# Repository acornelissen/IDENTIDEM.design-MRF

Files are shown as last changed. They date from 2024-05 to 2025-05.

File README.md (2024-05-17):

# IDENTIDEM.design M(edium Format) (R)ange(F)inder

**Before anything else, a big thank you to Oscar from Panomicron for making the CAD files for his [Thulium 6x9](https://www.panomicron.com/thulium) available for download. This camera is a heavily modified version of the Thulium, and wouldn't exist if it wasn't for Oscar's excellent work.**

My goal for this camera was to build _my_ ideal medium format rangefinder using what I learned from designing and building the LRF45, with no limits on complexity, cost, and time. As I kept working on it, it evolved and evolved, and I think I've finally reached that goal.

The detailed build guide should drop soon(ish). For now though, everything you need to build one of your own modern medium format rangefinders is in this repository.

## Features
- Uses "LiDAR" to measure distance to subject (not true LiDAR, but a ToF sensor that uses a focused IR LED array) 
- Can be used with any Mamiya Universal Press lens and couples to the original lens rangefinder mechanism with a high-precision linear position sensor
- This means that the lens position and distance measured is electronically coupled, making this the first multi-lens, electronically coupled rangefinder that I know of
- In addition, there is an intuitive in-camera lens calibration routine to make sure your camera and lens work together perfectly
- Multi-format, with masks for 6x7, 6x6, 6x4.5 and 35mm Panoramics
- Uses a high-precision rotary encoder coupled to the take-up spool to count revolutions, which is then used to accurately count frames regardless of selected format
- Built-in lightmeter
- Built-in accelerometer / gyro
- In-viewfinder OLED display with:
  - Lightmeter information: Selected ISO, selected aperture, and calculated shutter speed
  - Lens focus distance
  - Distance to subject
  - Frame lines that adjust according to selected lens
  - Masking that adjusts to selected format
  - Reticle for focus that indicates focus accuracy as lens focus distance and distance to subject converges
  - Horizon indicator
- External OLED display with:
  - Frame counter
  - Battery life percentage
  - Selected format
  - Selected lens
- Open source! 

## Bill of Materials
See the Build Guide PDF for the BoM. 

---
🍺 <strong><a href="https://paypal.me/albertcor">Buy me a beer</a></strong> if you'd like to say thank you.

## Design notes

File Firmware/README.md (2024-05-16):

This is a Arduino C++ rewrite of the LRF45 CircuitPython code that was adapted for use in my medium format LiDAR rangefinder. 
With the amount of sensors I am using on this camera, as well as needing to drive two displays, the CircuitPython performance was not acceptable, even running on a better MCU.

This code was built for the Adafruit Feather ESP32-S3 (I am using the 4MB Flash 2MB PSRAM version, but the one without PSRAM should work just as well). It's a nice board with a built in LiPO charger and battery monitor, 
so no need to faff about with voltage dividers and guesstimate how much battery is left.

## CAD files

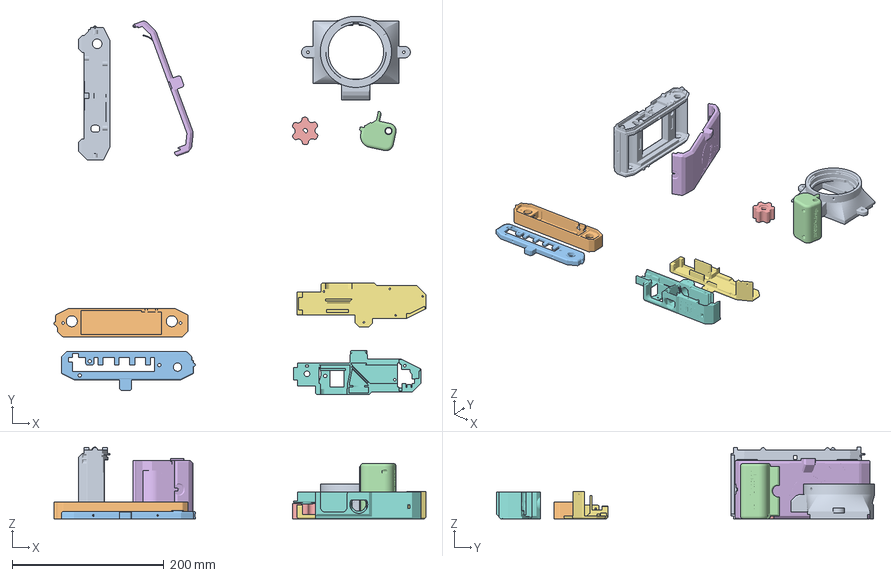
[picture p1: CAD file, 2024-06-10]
OrcaSlicer/main-parts.3mf
490.9 x 499.4 x 94.8 mm
body-main
body-bottom
top-plate
grip
advance-knob
door-back
viewfinder-cover
viewfinder
lenscone-mamiya-press-thick-wall

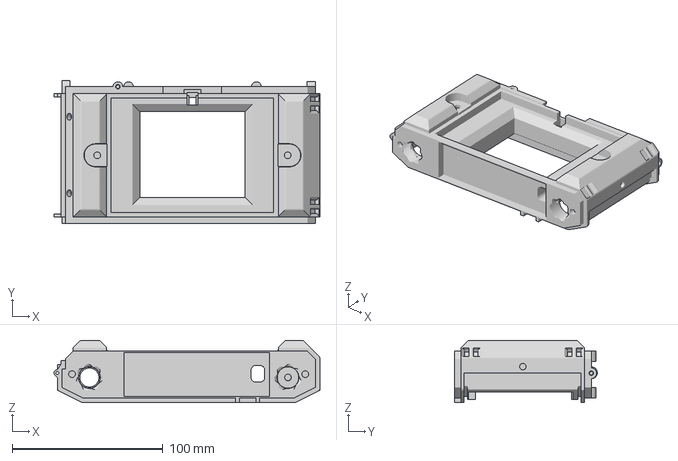
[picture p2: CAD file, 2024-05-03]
3MF/Main Parts/body-main.3mf
176.8 x 94.8 x 41.5 mm

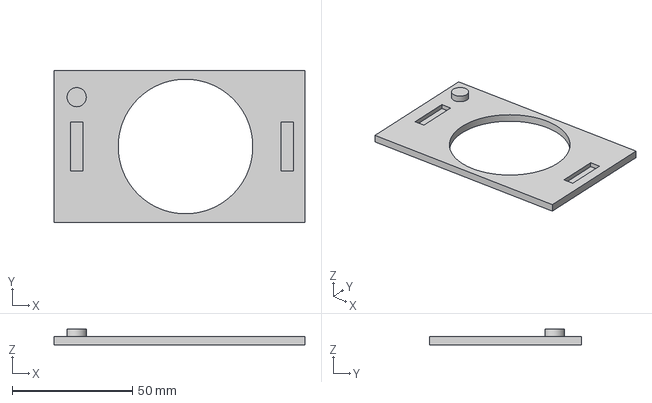
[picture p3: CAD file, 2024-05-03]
3MF/Film Masks/6x6 Circle.3mf
104.5 x 63.1 x 6.50 mm

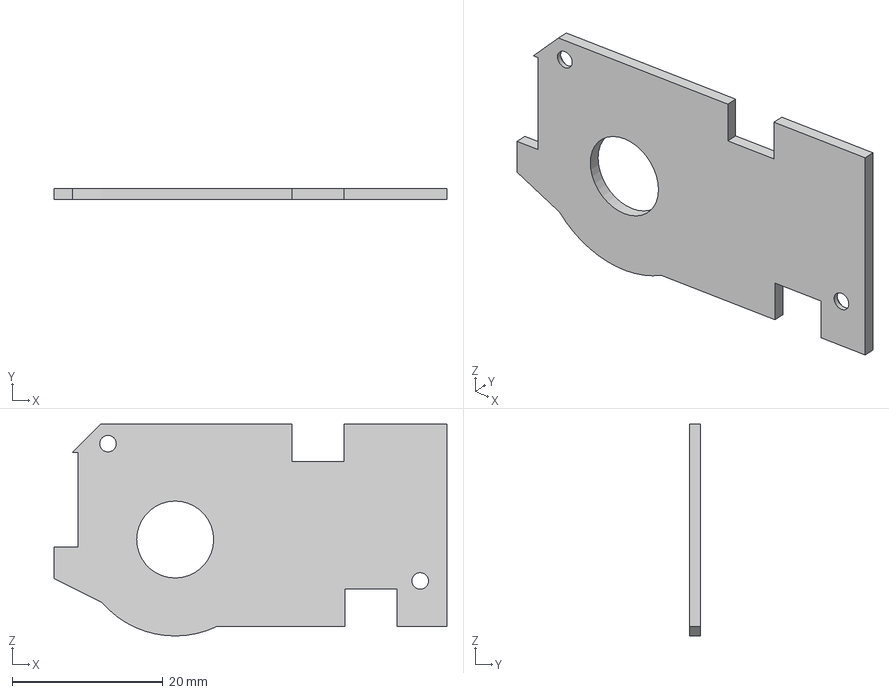
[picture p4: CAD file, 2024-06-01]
3MF/Fine Parts/advance-plate.3mf
52.1 x 1.50 x 28.1 mm

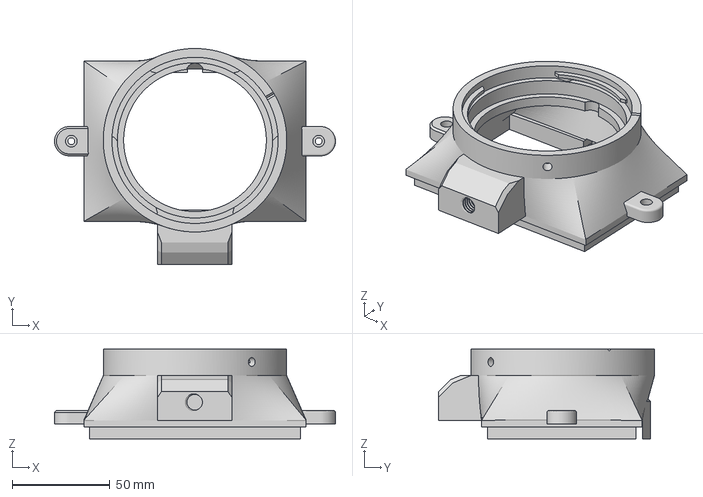
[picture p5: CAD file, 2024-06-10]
3MF/Main Parts/lenscone-mamiya-press.3mf
143.8 x 110.5 x 46.0 mm

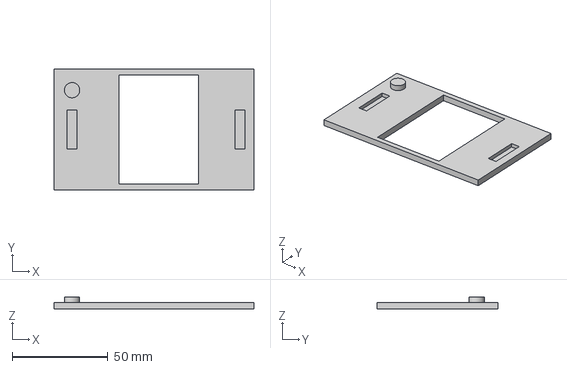
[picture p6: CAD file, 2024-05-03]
3MF/Film Masks/6x4.5.3mf
104.5 x 63.1 x 6.50 mm

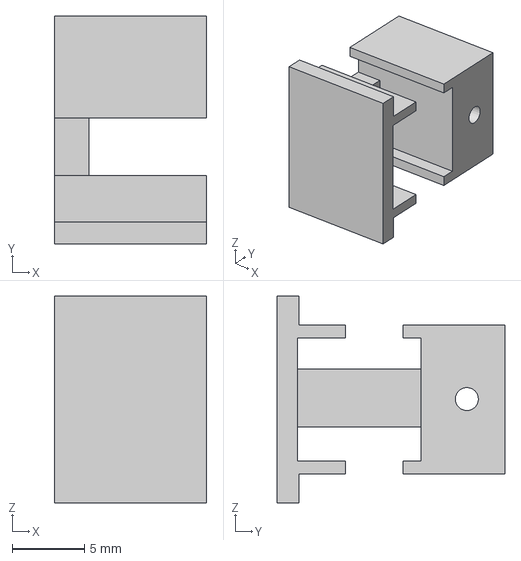
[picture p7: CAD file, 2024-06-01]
3MF/Fine Parts/button-plate.3mf
10.5 x 15.8 x 14.3 mm

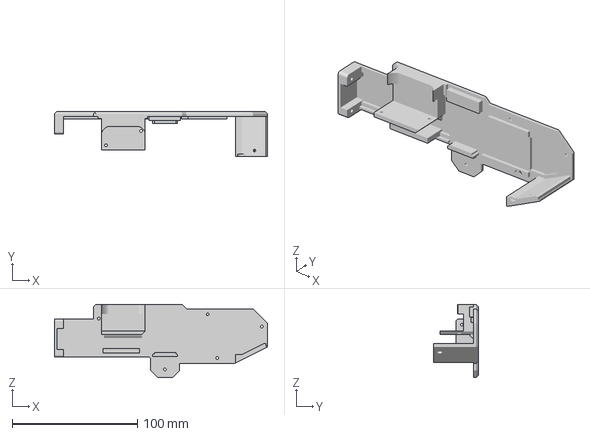
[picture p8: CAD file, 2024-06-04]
3MF/Main Parts/viewfinder-cover.3mf
170.1 x 36.2 x 58.4 mm

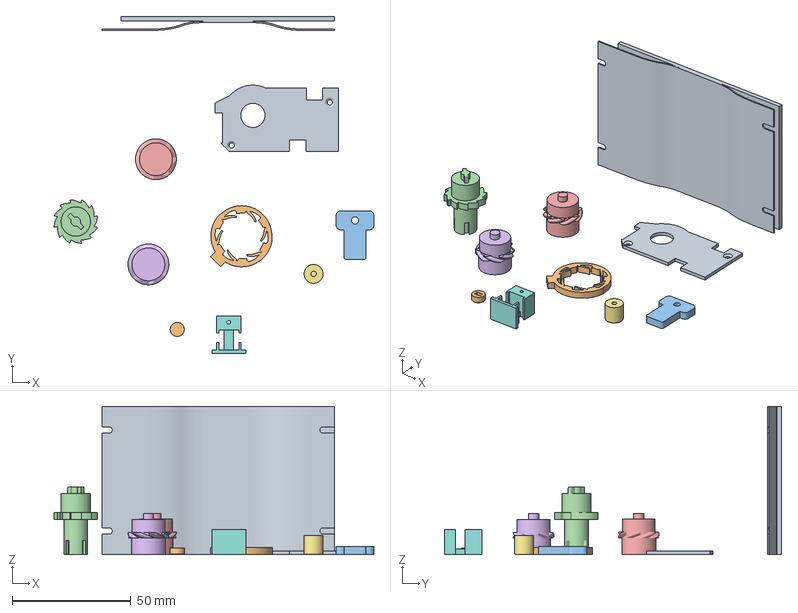
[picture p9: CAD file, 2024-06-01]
OrcaSlicer/fine-parts.3mf
135.0 x 142.1 x 62.6 mm
pressure-plate
advance-ratchet
spool-key (optional)
advance-post
right (from back) spool
left (from back) spool
sensor-nubbin
advance-plate
button

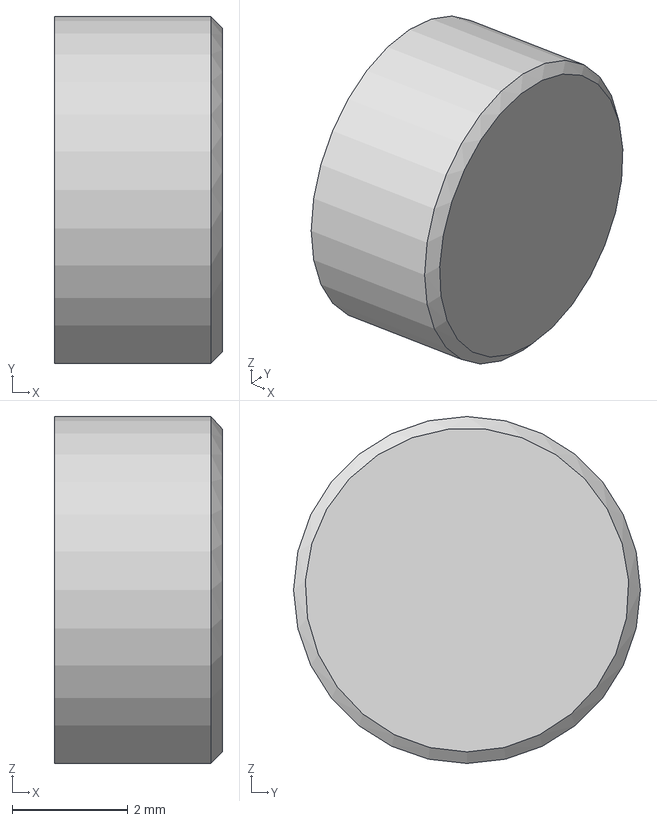
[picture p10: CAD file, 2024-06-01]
3MF/Fine Parts/button.3mf
2.91 x 6.00 x 6.00 mm

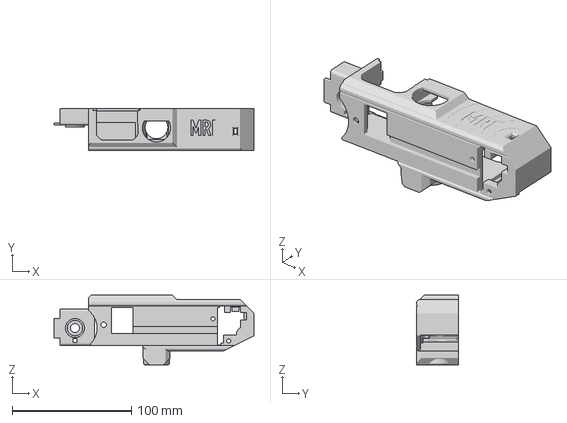
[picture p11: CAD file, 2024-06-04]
3MF/Main Parts/viewfinder.3mf
168.0 x 35.6 x 58.4 mm

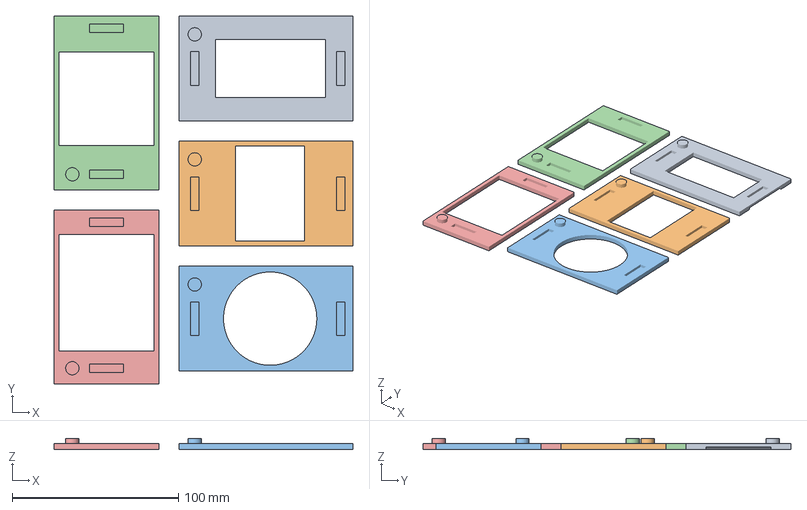
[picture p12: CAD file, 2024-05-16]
OrcaSlicer/film-masks.3mf
179.6 x 221.0 x 6.50 mm
35mm Pano
6x4.5
6x6 Circle
6x6
6x7

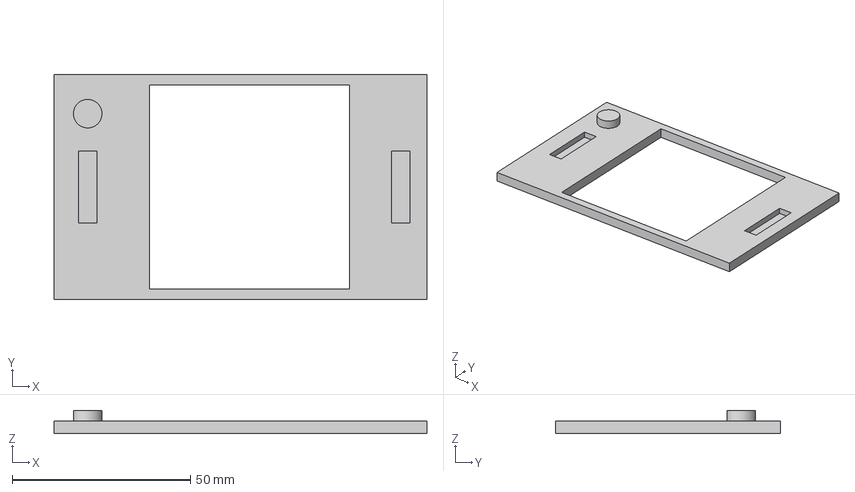
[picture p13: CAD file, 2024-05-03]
3MF/Film Masks/6x6.3mf
104.5 x 63.1 x 6.50 mm

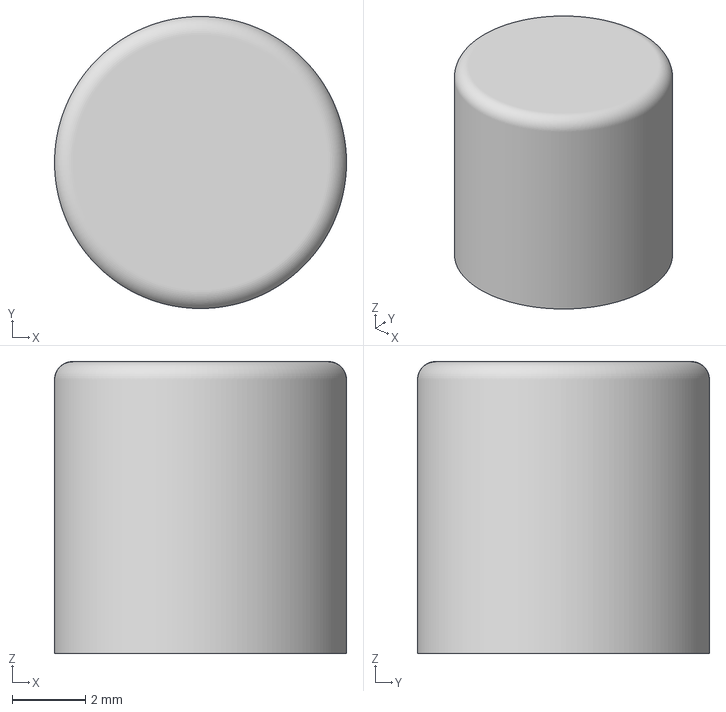
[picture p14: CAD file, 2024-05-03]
3MF/Fine Parts/sensor-nubbin.3mf
8.00 x 8.00 x 8.00 mm

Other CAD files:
3MF/Film Masks/35mm Pano.3mf
3MF/Main Parts/door-back.3mf
3MF/Film Masks/6x7.3mf
3MF/Fine Parts/pressure-plate.3mf
3MF/Fine Parts/advance-post.3mf
3MF/Fine Parts/advance-ratchet.3mf
3MF/Fine Parts/left (from back) spool.3mf
3MF/Fine Parts/right (from back) spool.3mf
3MF/Fine Parts/spool-key (optional).3mf
3MF/Main Parts/advance-knob.3mf
3MF/Main Parts/body-bottom.3mf
3MF/Main Parts/grip.3mf
3MF/Main Parts/top-plate.3mf

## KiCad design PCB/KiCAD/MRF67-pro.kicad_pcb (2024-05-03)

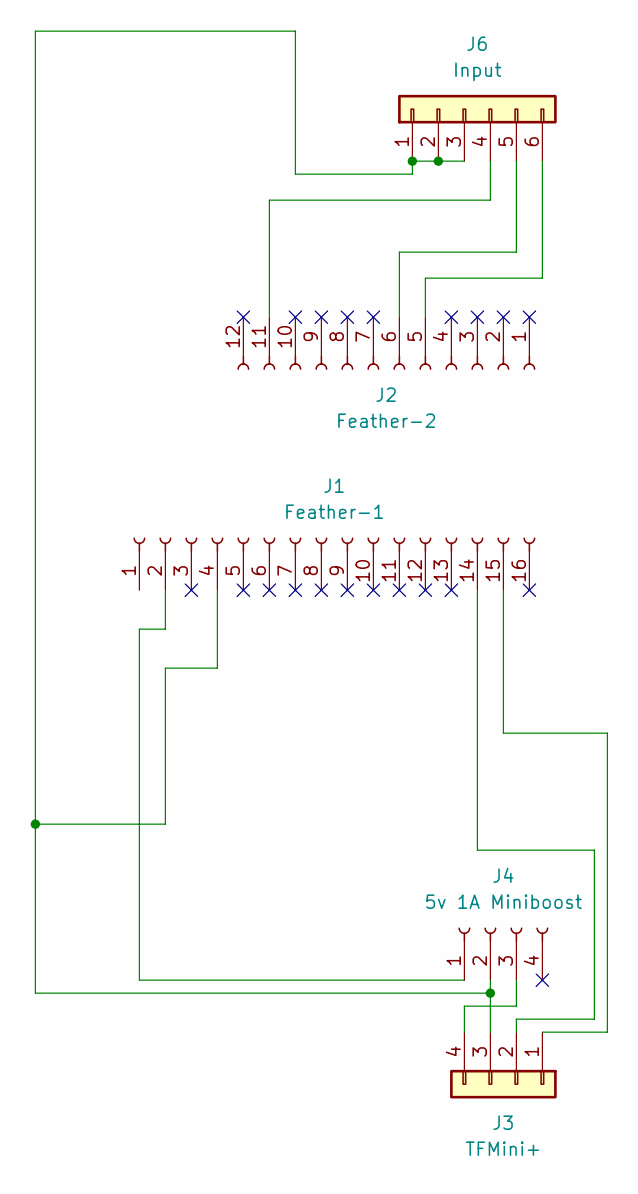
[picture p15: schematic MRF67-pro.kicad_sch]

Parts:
J1: Feather-1; PinHeader_1x16_P2.54mm_Vertical
J2: Feather-2; PinHeader_1x12_P2.54mm_Vertical
J3: TFMini+; JST_XH_B4B-XH-A_1x04_P2.50mm_Vertical
J4: 5v 1A Miniboost; PinHeader_1x04_P2.54mm_Vertical
J6: Input; JST_XH_B6B-XH-AM_1x06_P2.50mm_Vertical

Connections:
unnamed: J1.2, J4.1
unnamed: J1.4, J3.3, J4.2, J6.1, J6.2, J6.3
unnamed: J1.14, J3.2
unnamed: J1.15, J3.1
unnamed: J2.5, J6.6
unnamed: J2.6, J6.5
unnamed: J2.11, J6.4
unnamed: J3.4, J4.3

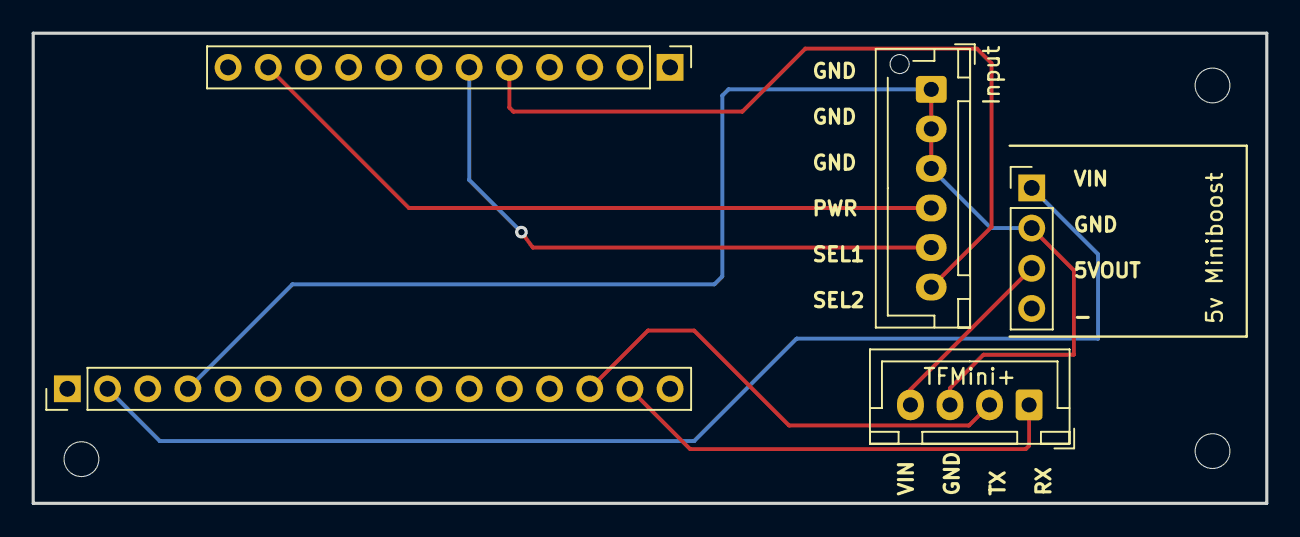
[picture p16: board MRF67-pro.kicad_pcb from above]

Board: 2 copper layers, 78.0 x 29.7 mm, 5 parts (0 on the bottom side), 8 nets.

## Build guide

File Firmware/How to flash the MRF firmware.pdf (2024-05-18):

# How to flash the MRF firmware

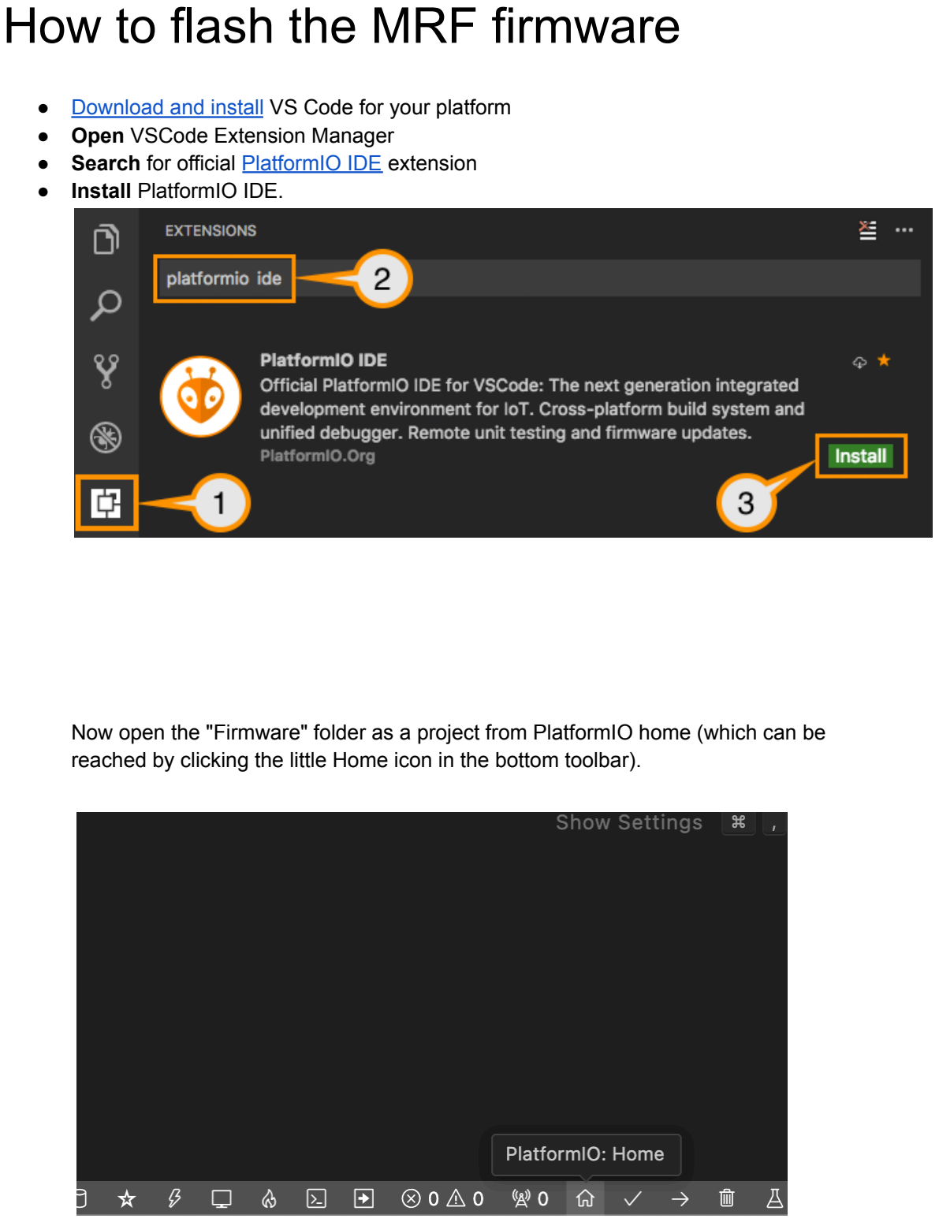
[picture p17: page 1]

- Download and install (https://code.visualstudio.com/download) VS Code for your platform
- Open VSCode Extension Manager
- Search for official PlatformIO IDE (https://marketplace.visualstudio.com/items?itemName=platformio.platformio-ide) extension
- Install PlatformIO IDE.

Now open the "Firmware" folder as a project from PlatformIO home (which can be reached by clicking the little Home icon in the bottom toolbar).

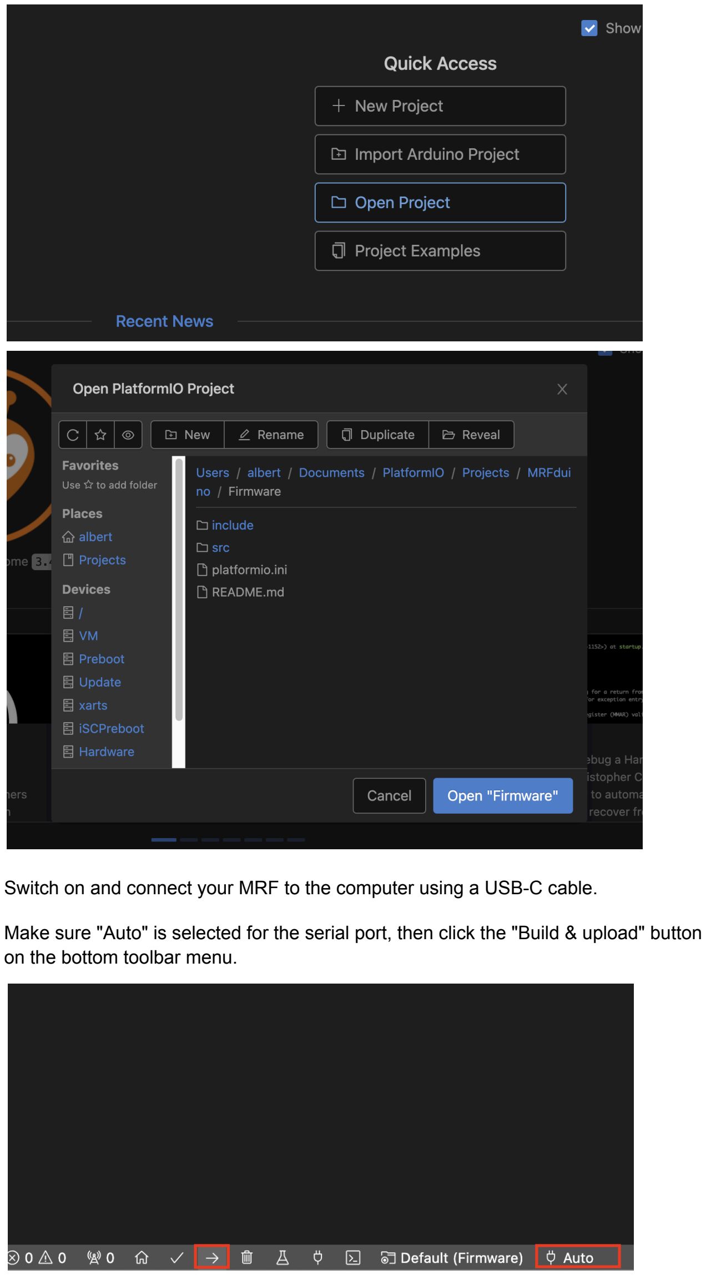
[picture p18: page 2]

Switch on and connect your MRF to the computer using a USB-C cable.

Make sure "Auto" is selected for the serial port, then click the "Build & upload" button on the bottom toolbar menu.

Watch the magic as the firmware is built and uploaded (if all goes well).

Once done, disconnect your MRF from the computer, switch it off, then on again and you should see the camera boot up on the external display.

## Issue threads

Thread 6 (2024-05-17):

No variations for beam splitter plate in 1.2mm thickness

siawyoung, 2024-05-17:
Hi, I'm accessing the link for plate beam splitter but it doesn't seem like they make it in 1.2mm thickness (or maybe it's not available anymore). Is 1.1mm ok?

https://www.ebay.co.uk/itm/225028201670

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

acornelissen, 2024-05-17:
@siawyoung that's a typo on my end, thanks for pointing it out! 1.1mm is perfect. I'll fix the BoM.

Closed 2024-05-17.

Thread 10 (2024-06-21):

Seesaw Address is set to non-default value in mrfconstants.h

masonjar3883, 2024-06-21:
While doing some initial checkouts, I noted my MRF seemed to be stuck in a reboot loop.  After some troubleshooting, I narrowed the issue down to the Seesaw I2C address as defined in mrfconstants.h.  The current value is set a non-default address (0x38) which is for a configuration with the A1 jumper closed on the Seesaw encoder.  I set the value back to the default (0x36 - no jumpers closed), which resolved my issue.

Suggest others may benefit from a comment in the code / build guide referencing the Adafruit pinout information (https://learn.adafruit.com/adafruit-i2c-qt-rotary-encoder/pinouts), or perhaps a note in the build instructions to close jumper A1 on their Seesaw Encoders if they do not wish to modify the I2C address in the code.

Other than that, the build guide and the firmware have been fantastic!

acornelissen, 2024-06-21:
@masonjar3883 ah, good catch! I think easiest would just be to set this back to the default in the code, which I've done.
I had a bad batch and had tried everything to to get them to work, I guess this was just a holdover from that.

I'm super happy to hear the build's going well. I'd love to see the pictures you eventually make with the MRF - so please pop over a place I can see your photos if you don't mind sharing!

Closed 2024-06-21.

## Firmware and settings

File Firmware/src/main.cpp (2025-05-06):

// IDENTIDEM.design (M)edium Format (R)ange(F)inder firmware

#include <Arduino.h>
#include <Wire.h>
#include <Adafruit_SSD1306.h>
#include <Adafruit_SH110X.h>
#include <Adafruit_MAX1704X.h>
#include <Adafruit_ADS1X15.h>
#include <Adafruit_MPU6050.h>
#include <Adafruit_Sensor.h>
#include <TFMPlus.h>
#include <BH1750.h>
#include <U8g2_for_Adafruit_GFX.h>
#include <Bounce2.h>
#include <Adafruit_seesaw.h>
#include <seesaw_neopixel.h>
#include <Preferences.h>
#include <math.h>

#include "driver/rtc_io.h"
#include "esp_wifi.h"
#include "esp_bt.h"

//Constants and variables
#include <mrfconstants.h>
#include <lenses.h>
#include <formats.h>
#include <globals.h>

// Init hardware
#include <hardware.h>

// Functions
#include <helpers.h>
#include <cyclefuncs.h>
#include <setfuncs.h>
#include <interface.h>
#include <inputs.h>

// Setup and loop functions
// ---------------------
void setup()
{

  Serial.begin(115200); // Initializing serial port

  esp_wifi_stop(); // Stop WiFi to save power
  esp_bt_controller_disable(); // Stop Bluetooth to save power

  loadPrefs();

  // Initialise inputs
  ads1015.begin();
  mpu.begin();
  ads1015.setGain(GAIN_ONE); 
  lbutton.attach(9, INPUT_PULLUP);
  lbutton.interval(5);
  lbutton.setPressedState(LOW);
  rbutton.attach(10, INPUT_PULLUP);
  rbutton.interval(5);
  rbutton.setPressedState(LOW);

  delay(1000); // Slight delay or the displays won't work
  display.begin(SCREEN_ADDRESS, true); // Address 0x3D default
  display.oled_command(0xC8);
  display.setRotation(3);
  u8g2.begin(display);
  display.clearDisplay();
  display.display();

  delay(500); // Slight delay or the displays won't work

  display_ext.begin(SSD1306_SWITCHCAPVCC, SCREEN_ADDRESS_EXT);

  // Boot up sceen
  display_ext.clearDisplay();
  display_ext.setTextSize(2); // Draw 2X-scale text
  display_ext.setTextColor(SSD1306_WHITE);
  display_ext.setCursor(20, 10);
  display_ext.print(F("MRF "));
  display_ext.println(FWVERSION);
  display_ext.display();

  delay(1000);

  u8g2_ext.begin(display_ext);
  display_ext.clearDisplay();
  display_ext.display();

  // Start the LiDAR sensor
  lidarSerial.begin(115200, SERIAL_8N1, RXD2, TXD2);
  delay(20);
  tfminiplus.begin(&lidarSerial);

  // Clear the moving average arrays
  for (int i = 0; i < SMOOTHING_WINDOW_SIZE; i++)
  {
    samples[0][i] = 0;
    samples[1][i] = 0;
  }

  // Start the battery gauge and lightmeter
  maxlipo.begin();
  lightMeter.begin();

  // Seesaw NEOpixel
  if (sspixel.begin(SEESAW_ADDR)) {
    delay(10);
    sspixel.setBrightness(80);
    sspixel.show();
  }


  // Start the encoder
  if (encoder.begin(SEESAW_ADDR)) {
    delay(10);
    encoder.setEncoderPosition(encoder_value);
    encoder.enableEncoderInterrupt();
  }

}

void loop()
{
  
  if (millis() - lastActivityTime > SLEEPTIMEOUT) { // Step 3
    sleepMode = true;
  }

  checkButtons();
  setFilmCounter();

  if (sleepMode == true)
  {
    toggleLidar(false);
    drawSleepUI();
  }
  else { 
    toggleLidar(true);
    
    if (ui_mode == "main")
      { 
        setDistance();
        setLensDistance();
        setVoltage();
        setLightMeter();
        drawMainUI();
      }
      else if (ui_mode == "config")
      {
        drawConfigUI();
      }
      else if (ui_mode == "calib")
      {
        drawCalibUI();
      }
      drawExternalUI();
  }
}
// ---------------------

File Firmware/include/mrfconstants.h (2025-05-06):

#ifndef MRFCONSTANTS_H_
#define MRFCONSTANTS_H_

// Constants
#define FWVERSION "5.0" // From original file
#define SLEEPTIMEOUT 60000

#define RXD2 RX // These were commented out, kept as such
#define TXD2 TX

#define SS_NEOPIX 6
#define SEESAW_ADDR 0x36

#define LENS_ADC_PIN 0

#define SCREEN_WIDTH 128
#define SCREEN_HEIGHT 128
#define SCREEN_HEIGHT_EXT 32
#define OLED_RESET -1
#define SCREEN_ADDRESS 0x3D
#define SCREEN_ADDRESS_EXT 0x3C

#define SMOOTHING_WINDOW_SIZE 10

#define RETICLE_OFFSET_X -7
#define RETICLE_OFFSET_Y 3
#define CLOSE_FOCUS 100
#define LIDAR_OFFSET 10

#define DISTANCE_MIN 15
#define DISTANCE_MAX 12


extern const int ISOS[];
extern const int ISOS_SIZE; 
extern const float CALIB_DISTANCES[];
extern const int CALIB_DISTANCES_SIZE;

#define K_VALUE 20 

#endif // MRFCONSTANTS_H_

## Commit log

2024-04-10 Reset LiDAR on startup and set frame rate to 20HZ.
    [main.cpp]
2024-04-10 Fix formatting and tab spacing.
    [main.cpp]
2024-04-19 Replace 128x64 SSD1306 with SH1107 128x128 OLED - and cheap rotary encoder breakout with Adafruit STEMMA I2C Seesaw Rotary Encoder breakout.
    [main.cpp, mrfconstants.h]
2024-04-20 Improvements
    - Tie framelines to lens and film format
    - Fix setting encoder value
    - Reduce smoothing window size to speed up lens distance feedback
    - General UI improvements for bigger viewfinder
    [main.cpp, mrfconstants.h]
2024-04-22 Even more improvements and updating of defaults
    - All lenses now have their own correct framelines, except for 55mm and 65mm which are identical, because my VF optics don't cover 55mm
    - Masking for formats now shrink to the relevant frame lines
    - We have a Neopixel RGB LED on the rotary encoder breakout board, so might as well use it
    - Add a LIDAR_OFFSET constant and apply it to the distance measured
    [main.cpp, mrfconstants.h]
2024-04-29 Start counting frames two clicks earlier.
2024-05-01 We now use an external ADC instead of the ESP32's noisy internal ADC
    Also update hardware info in readme to be more precise and include links.
2024-05-03 Add PCB, STEP and 3MF files, and re-organize things a bit.
    [35mm Pano.3mf, 6x4.5.3mf, 6x6 Circle.3mf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]
2024-05-16 Add build guide and Orcaslicer files.
    [film-masks.3mf, fine-parts.3mf, main-parts.3mf]
2024-05-17 Add three rotations of the take up spool for each 120 format to make sure we get a whole first frame.
2024-05-17 Chane typo for beam splitter width from 1.2mm to 1.1mm
2024-05-17 Sorted LiDAR readings.
2024-05-24 Add sleepmode and snap frame count.
    [main.cpp]
2024-05-24 Improve device sleep mode and frame counter snapping.
    [main.cpp, mrfconstants.h]
2024-05-27 Modify advance plate to not fit so snug
    [advance-plate.3mf]
2024-05-27 Update plate in step file as well.
2024-05-28 Add note / section about power management and buttons.
2024-05-29 A buncha buncha power-saving changes.
    - Disable WiFI and BT on startup - not being used at the moment.
    - Implement proper deep sleep: (L) button for 5 seconds "turns off" the camera, (R) for 5 seconds then "turns it back on" again.
2024-05-29 toggle lidar for deep sleep as well
2024-05-30 A few updates
    - Put deepsleep behind a toggle constant
    - make sure all button presses update last activity time
    - advance knob rotary encoder now also brings camera out of "light sleep"
    - bring back bootup screen on first start
2024-06-01 Update a few parts, specifically a new mount for the better switch. Also update build guide.
    [advance-plate.3mf, button-plate.3mf, button.3mf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]
2024-06-04 Increased wall thicknesses and changed a few bits for MJF printing.
    The previous lens cone and film door were not 100% light tight when printed with MJF (or at least the ones I had printed by JLCPCB were not), which would fog the current frame in bright sunlight over time. Add hopefully enough thickness to fix that without changing the geometry of the camera too much.
    Added some extra support to the LiDAR mount.
    Added an extra channel for routing wire below the viewfinder.
    [door-back.3mf, lenscone-mamiya-press.3mf, main-parts.3mf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]
2024-06-09 Update lenscone mount diameter.
    [lenscone-mamiya-press.3mf, main-parts.3mf]
2024-06-10 More updates to lens mount diameters.
    [lenscone-mamiya-press.3mf, main-parts.3mf]
2024-06-21 Fix for issue #10
    https://github.com/acornelissen/IDENTIDEM.design-MRF/issues/10
    [mrfconstants.h]
2024-06-21 Add 6x9 sensor values, commented, for a future version of the camera.
2024-08-02 Fix some typos and apply calibrated reticle position.
    [mrfconstants.h]
2024-10-24 Properly soldered encoders will not read a negative value - fix this in the code.
    [main.cpp, mrfconstants.h]
2024-11-07 Better handling of lidar status.
2024-12-30 More accurate frame spacing.
    Bringing over the frame spacing sensor values from v2, which were calculated with help from Oscar Oweson's spool maths spreadsheet.
